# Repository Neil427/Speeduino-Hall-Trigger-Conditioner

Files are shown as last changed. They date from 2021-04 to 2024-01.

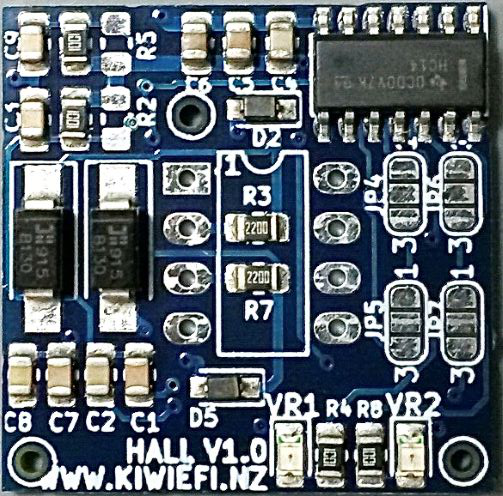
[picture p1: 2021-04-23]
PICS/KiwiEfiHallV1Top.jpeg

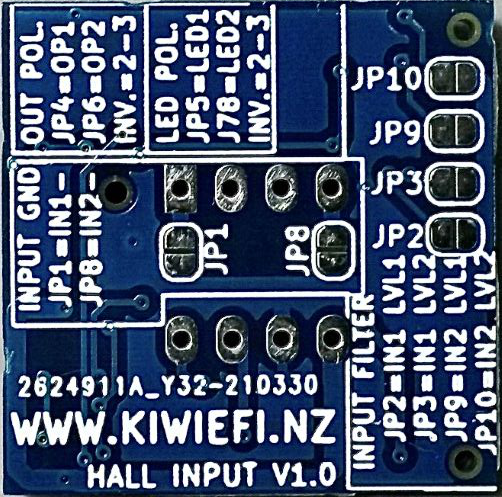
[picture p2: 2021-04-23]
PICS/KiwiEfiHallV1Bottom.jpeg

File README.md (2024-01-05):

# KiwiEFI-HallSensor-Conditioner
Speeduino Hall sensor conditioner board with buffering:   
This KiwiEfi project is a dual Hall effect sensor conditioner board designed with the form factor to plug into a Speeduino ECU
The conditioner has many features to help diagnostics, protect the mcu, and configuration for different engines.
- Dual Channel
- Output buffering to drive the mcu and protect the mcu from overvoltage sources
- Crank and Cam trigger LED indication
- Selectable signal filtering
- Selectable signal polarity invert function
- Selectable inversion of the indicator LEDs to suit the polarity of the input signal



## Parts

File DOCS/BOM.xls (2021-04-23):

Comment | Designator | Footprint | LCSC Part Number
4N7 50V | C1, C7 | 0805 | C1744
10N 50V | C2, C8 | 0805 | C1710
1N 50V | C3, C9 | 0805 | C46653
100N 50V | C4 | 0805 | C49678
10uF10V | C5 | 0805 | C15850
1UF 50V | C6 | 0805 | C28323
B130-13-F SMA | D1, D4 | SMA | C134423
MM3Z5V1ST1G | D2, D5 | SOD-323 | C152524
LED | D3, D6 | 0805 | C2296
1K | R1, R4, R6, R8 | 0805 | C17513
1K (Optional) | R2,R5 | 0805
220 | R3, R7 | 0805 | C17557
SN74HC14N | U1 | SOIC-14 | C347584

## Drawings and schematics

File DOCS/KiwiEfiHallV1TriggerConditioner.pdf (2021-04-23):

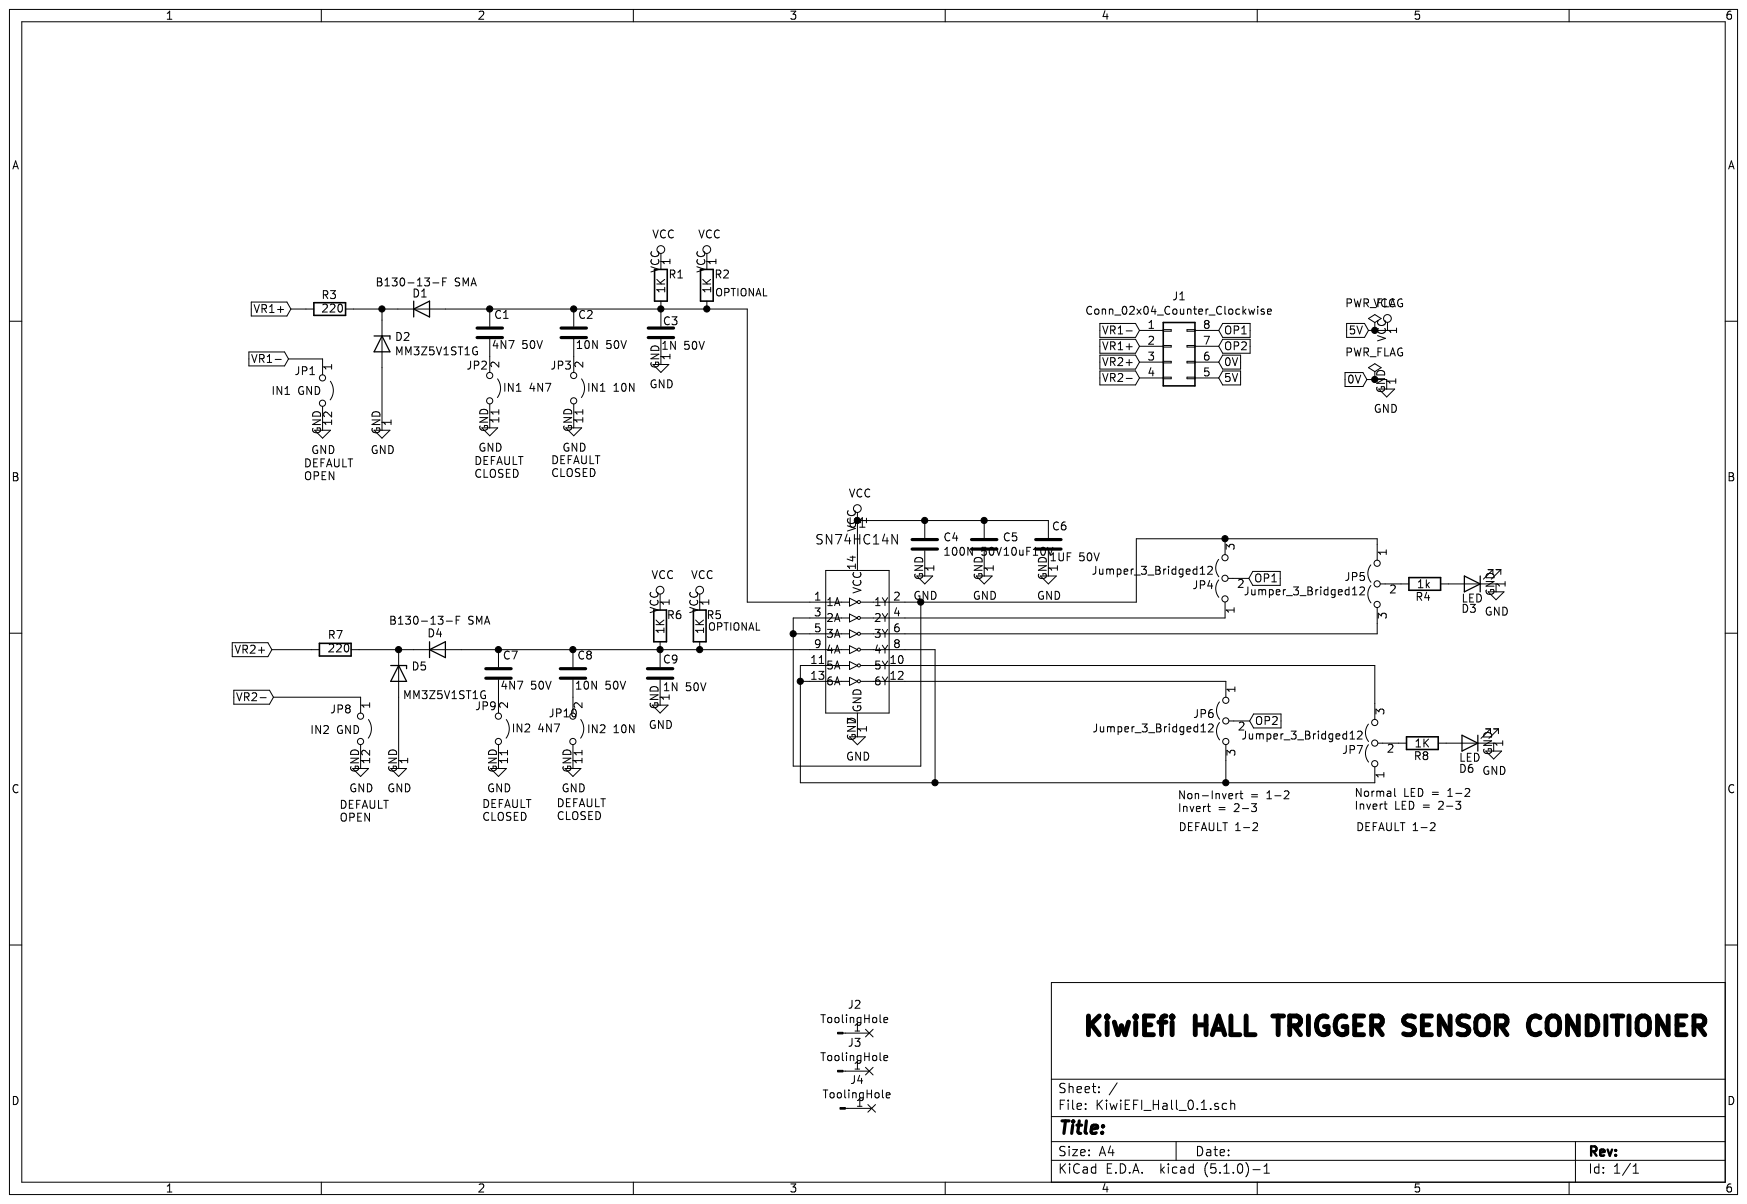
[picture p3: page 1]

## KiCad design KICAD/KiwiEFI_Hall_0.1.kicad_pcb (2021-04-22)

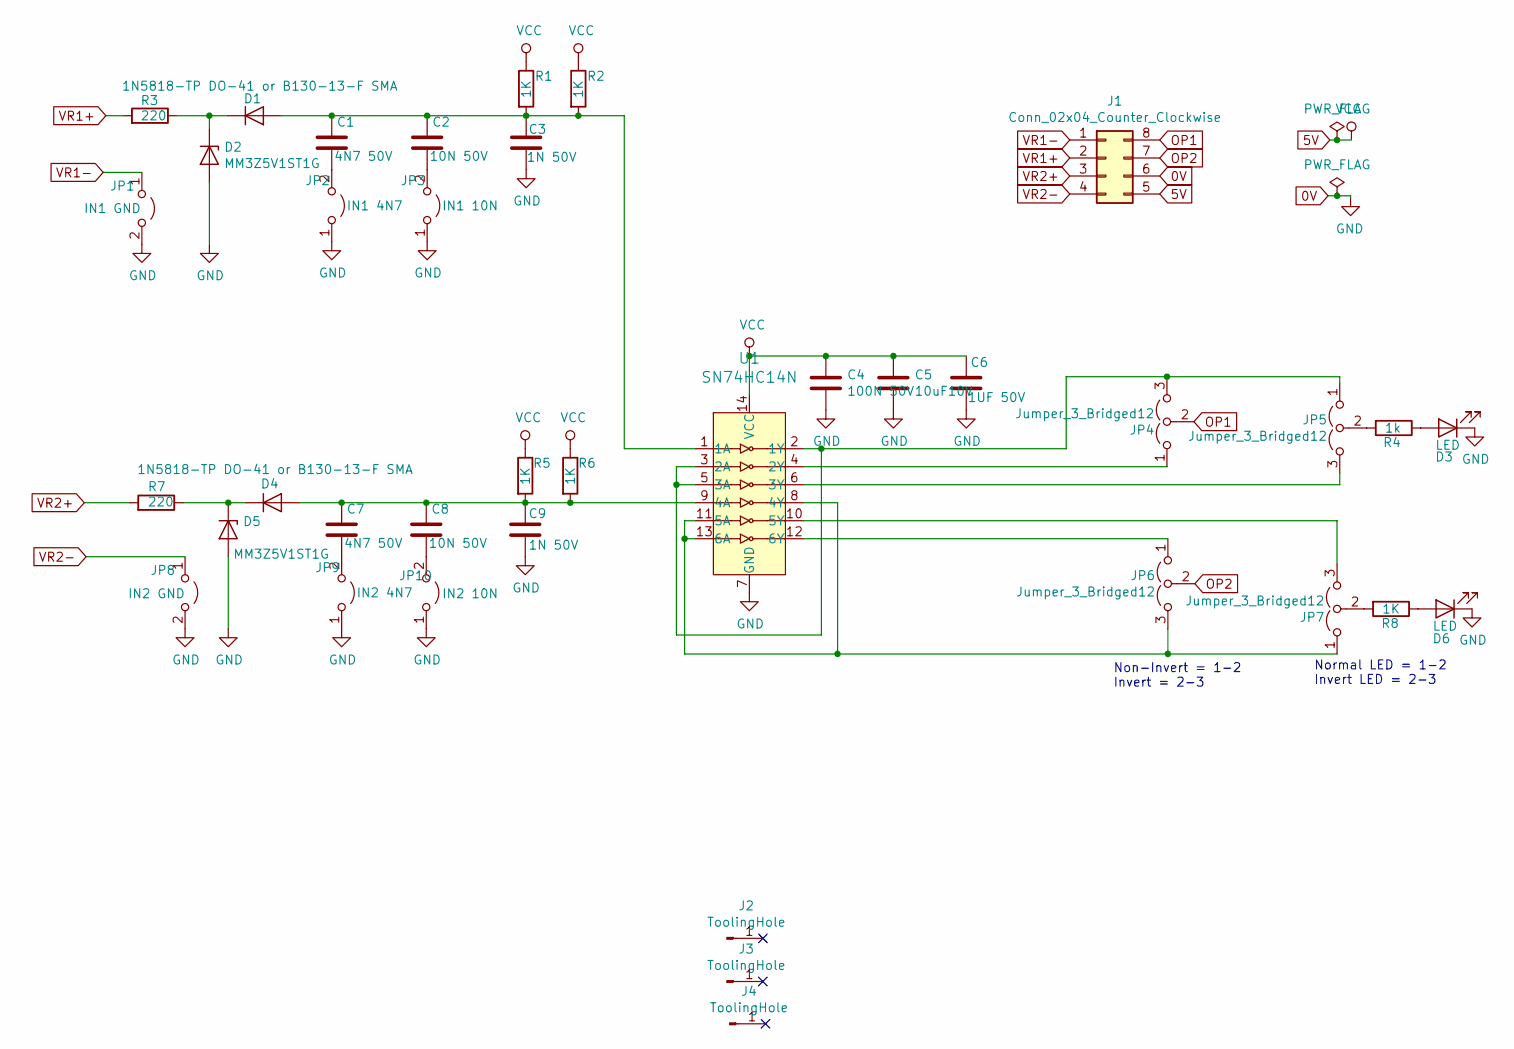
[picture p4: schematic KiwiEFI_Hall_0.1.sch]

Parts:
C1, C7: 4N7 50V; C_0805_2012Metric_Pad1.15x1.40mm_HandSolder
C2, C8: 10N 50V; C_0805_2012Metric_Pad1.15x1.40mm_HandSolder
C3, C9: 1N 50V; C_0805_2012Metric_Pad1.15x1.40mm_HandSolder
C4: 100N 50V; C_0805_2012Metric_Pad1.15x1.40mm_HandSolder
C5: 10uF10V; C_0805_2012Metric_Pad1.15x1.40mm_HandSolder
C6: 1UF 50V; C_0805_2012Metric_Pad1.15x1.40mm_HandSolder
D1, D4: 1N5818-TP DO-41 or B130-13-F SMA; D_SMA_Handsoldering
D2, D5: MM3Z5V1ST1G; D_SOD-323_HandSoldering
D3, D6: LED; LED_0805_2012Metric_Pad1.15x1.40mm_HandSolder
J1: Conn_02x04_Counter_Clockwise; DIP-8_W7.62mm_LongPads
J2, J3, J4: ToolingHole
JP1: IN1 GND; SolderJumper-2_P1.3mm_Open_RoundedPad1.0x1.5mm
JP2: IN1 4N7; SolderJumper-2_P1.3mm_Open_RoundedPad1.0x1.5mm
JP3: IN1 10N; SolderJumper-2_P1.3mm_Open_RoundedPad1.0x1.5mm
JP4, JP5, JP6, JP7: Jumper_3_Bridged12; SolderJumper-3_P1.3mm_Open_RoundedPad1.0x1.5mm_NumberLabels
JP8: IN2 GND; SolderJumper-2_P1.3mm_Open_RoundedPad1.0x1.5mm
JP9: IN2 4N7; SolderJumper-2_P1.3mm_Open_RoundedPad1.0x1.5mm
JP10: IN2 10N; SolderJumper-2_P1.3mm_Open_RoundedPad1.0x1.5mm
R1, R2, R5, R6, R8: 1K; R_0805_2012Metric_Pad1.15x1.40mm_HandSolder
R3, R7: 220; R_0805_2012Metric_Pad1.15x1.40mm_HandSolder
R4: 1k; R_0805_2012Metric_Pad1.15x1.40mm_HandSolder
U1: SN74HC14N; SOIC-14_3.9x8.7mm_P1.27mm; MPN SN74HC14N; Digi-Key_PN 296-1577-5-ND

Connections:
0V: C3.2, C4.2, C5.2, C6.2, C9.2, D2.2 (A), D3.1 (K), D5.2 (A), D6.1 (K), J1.6, JP1.2 (B), JP2.1 (A), JP3.1 (A), JP8.2 (B), JP9.1 (A), JP10.1 (A), U1.7 (GND)
5V: C4.1, C5.1, C6.1, J1.5, R1.1, R2.1, R5.1, R6.1, U1.14 (VCC)
unnamed: C1.1, C2.1, C3.1, D1.2 (A), R1.2, R2.2, U1.1 (1A)
unnamed: C1.2, JP2.2 (B)
unnamed: C2.2, JP3.2 (B)
unnamed: C7.1, C8.1, C9.1, D4.2 (A), R5.2, R6.2, U1.9 (4A)
unnamed: C7.2, JP9.2 (B)
unnamed: C8.2, JP10.2 (B)
unnamed: D1.1 (K), D2.1 (K), R3.1
unnamed: D3.2 (A), R4.1
unnamed: D4.1 (K), D5.1 (K), R7.1
unnamed: D6.2 (A), R8.1
unnamed: JP4.1 (A), U1.4 (2Y)
unnamed: JP4.3 (B), JP5.1 (A), U1.2 (1Y), U1.3 (2A), U1.5 (3A)
unnamed: JP5.2 (C), R4.2
unnamed: JP5.3 (B), U1.6 (3Y)
unnamed: JP6.1 (A), U1.12 (6Y)
unnamed: JP6.3 (B), JP7.1 (A), U1.8 (4Y), U1.11 (5A), U1.13 (6A)
unnamed: JP7.2 (C), R8.2
unnamed: JP7.3 (B), U1.10 (5Y)
OP1: J1.8, JP4.2 (C)
OP2: J1.7, JP6.2 (C)
VR1+: J1.2, R3.2
VR1-: J1.1, JP1.1 (A)
VR2+: J1.3, R7.2
VR2-: J1.4, JP8.1 (A)

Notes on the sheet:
Non-Invert = 1-2 Invert = 2-3
Normal LED = 1-2 Invert LED = 2-3

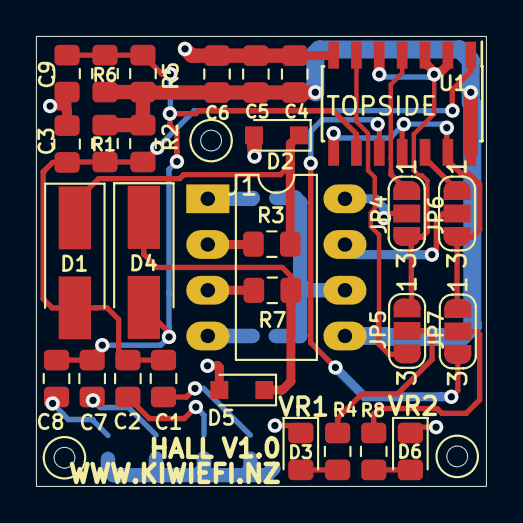
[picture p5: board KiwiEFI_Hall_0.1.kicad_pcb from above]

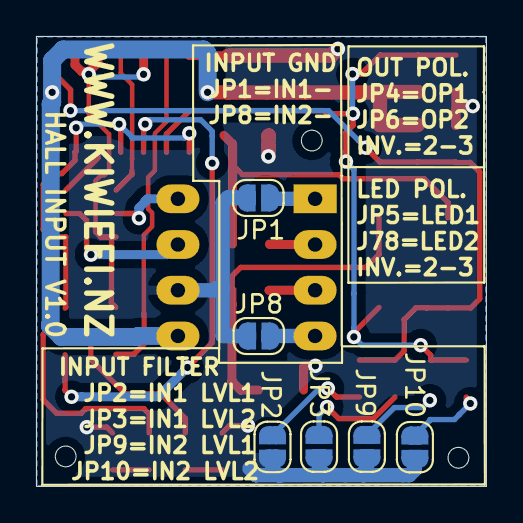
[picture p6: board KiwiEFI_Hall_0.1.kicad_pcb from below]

Board: 2 copper layers, 25.0 x 25.0 mm, 38 parts (6 on the bottom side), 26 nets.

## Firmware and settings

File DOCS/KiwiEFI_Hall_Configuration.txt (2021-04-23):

KiwiEfi HALL TRIGGER CONDITIONER CONFIGURATION
Please refer to the schematic pdf
(Default) is as jumpered when purchased from KiwiEFI


INPUT GROUNDS
CNK-   JP1 when CLOSED grounds the Crank- (negative) input (Default)
CAM-   JP8 when CLOSED grounds the Cam- (negative) input  (Default)



INPUT FILTERS
CNK Filter   JP2 CLOSED = Level 1 filtering
                  JP3 CLOSED = Level 2 filtering
                  Both CLOSED = Level 3 filtering  (Default)


CAN Filter   JP9 CLOSED = Level 1 filtering
                 JP10 CLOSED = Level 2 filtering
                 Both CLOSED = Level 3 filtering  (Default)

The default setting is Level 3 (maximum filtering) which should be suitable for a sensor up to about 24 teeth
Level 2 should be suitable for a sensor of 24 - 48 teeth
Level 1 should be suitable for a sensor of 48 - 60+ teeth 

NOTE: - any filtering on the Speeduino board should be removed
          - pullups on the Speeduino board can be enabled or not, they have no effect



OUTPUT POLARITY 
CNK Polarity  JP4 1-2 = output signal is the same polarity as input  (Default)
                    JP4 2-3 = input to output signal is inverted 

CAM Polarity  JP6 1-2 = output signal is the same polarity as input  (Default)
                     JP6 2-3 = input to output signal is inverted 




LED POLARITY  
CNK LED Polarity JP5 1-2 = LED is turned on when input is negative  (Default)
                          JP5 2-3 = LED is turned on when input is positive

CAM LED Polarity JP7 1-2 = LED is turned on when input is negative  (Default)
                          JP7 2-3 = LED is turned on when input is positive
 



OPTIONAL RESISTORS R2 and R5 - the pullup resistors are 1K by default, by adding parralel resistors (R2 and R5) the pullup current can be increased if required.
 

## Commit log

2021-04-22 Added KIcad files
    [BOM.xls, KiwiEFI_Hall_0.1.kicad_pcb, KiwiEFI_Hall_0.1.sch]
2021-04-22 Update Schematic
    [KiwiEFI_Hall_0.1.sch]
2021-04-23 Doccumenting optional components
    [BOM.xls, KiwiEFI_Hall_0.1.sch]
2021-04-23 Added configuration document
    [KiwiEFI_Hall_Configuration.txt]
